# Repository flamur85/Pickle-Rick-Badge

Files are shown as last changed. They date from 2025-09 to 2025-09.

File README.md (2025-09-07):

# Pickle Rick Badge Project

## Description
This project is a custom DIY electronic badge inspired by the DEF CON badge community. The badge brings together lights, sound, and motorized elements to create an interactive show triggered by button presses. It’s both a fun hacker-style project and a learning platform for Raspberry Pi GPIO programming, event handling, and hardware hacking.

Beyond the visual and audio shows, this badge will also include **CTF (Capture the Flag) functionality**, allowing others to explore hidden challenges embedded into the badge’s code, hardware, or connected resources. The goal is to create a hands-on, puzzle-filled badge that fits right into the spirit of hacker conferences.

## Project Image

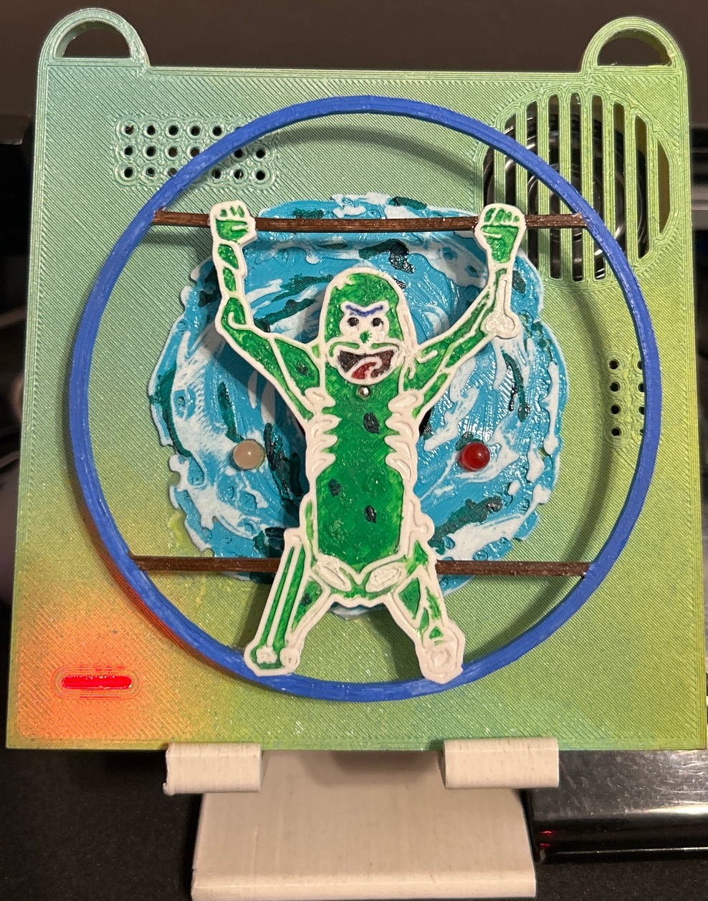
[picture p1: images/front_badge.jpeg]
Pickle Rick Badge


## Materials List
You’ll need the following to build and run the badge:

- **Raspberry Pi Zero 2 W**
- **MicroSD card** flashed with Raspberry Pi OS
- **Push buttons** (x5, GPIO wired)
- **LEDs** (x6, arranged in a circular pattern)
- **Resistors** for LEDs (220Ω or 330Ω recommended for use with Raspberry Pi GPIO)
- **DC hobby motor** (I got one from an old PS4 controller)
- **Diode** (1N4001 or similar, for motor flyback protection)
- **NPN transistor** (PN2222 or similar) for motor control
- **LiPo battery** (3Ah recommended. You can also use the battery from the PS4 controller too, though will not last as long...)
- **Boost converter** (to step up LiPo voltage to 5V for Pi)
- **Small physical single pole sliding switch** (for power control)
- **USB audio interface** (for audio output from the Pi)
- **Small audio amplifier module** (to drive the speaker)
- **Speaker** (8Ω, 0.5W–1W recommended)

For detailed assembly, wiring, and setup instructions, see [BUILD_GUIDE.md](BUILD_GUIDE.md).

## 3D Print Files
3D print files for the badge enclosure are included in this repository. The parts are designed for a Creality Ender 3 Pro and use PETG filament for durability and heat resistance. Feel free to modify or remix the files for your own setup!

## Sounds
A `audio_files` folder is included in this repository, containing the audio files used in the project. These sounds are played during the badge's interactive shows and events. You can replace them with your own audio clips or add new ones to customize your badge experience.

## Features
- **Startup Sound**: Plays "I'm Pickle Rick!" when the Pi boots up.
- **SSH Login Success Sound**: Plays "Son of a B*tch, I'm In!" on successful SSH login.
- **Power Level LEDs**: A set of LEDs displays the current battery level, giving a quick visual indication of remaining power.
- **SSH Login Failure Sound**: Plays "Disqualified!" on unsuccessful SSH login.
- **Power Light Indicator**: An LED illuminates when the badge is powered on, providing a clear visual status.
- **Button 1**: Triggers the *full show* (sound, lights, motor).
- **Button 2**: Triggers the *mini show* (lights + motor only).
- **Other 3 buttons**: Reserved for future expansion, including CTF triggers.
- **CTF Challenges**: Future versions will embed puzzles such as hidden flags in the code, badge interactions, or Easter eggs that encourage reverse engineering, etc.

## Inspired By
The design is inspired by **DEF CON electronic badges** and the broader **badge life community**, where creativity meets hacking culture. These badges often combine art, electronics, and puzzles to create unique experiences. The Pickle Rick Badge follows that tradition by blending fun shows with a CTF challenge element.

## Future CTF Functionality
- Hidden flags inside source code and hardware signals
- Triggered events requiring timing or button sequences
- Audio steganography challenges inside badge sounds
- Network-based puzzles (optional Wi-Fi CTF mode)

---

This project is meant to grow alongside community contributions and ideas. Whether you’re into hardware hacking, Python programming, or CTF puzzle design, this badge offers a platform to experiment and share.

For a step-by-step build walkthrough, see [BUILD_GUIDE.md](BUILD_GUIDE.md).

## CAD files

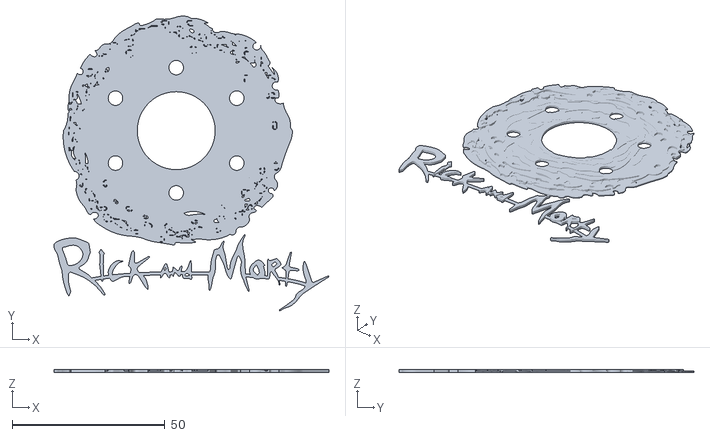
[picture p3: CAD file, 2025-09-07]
3d_print_files/Badge Bling.stl
90.0 x 96.5 x 1

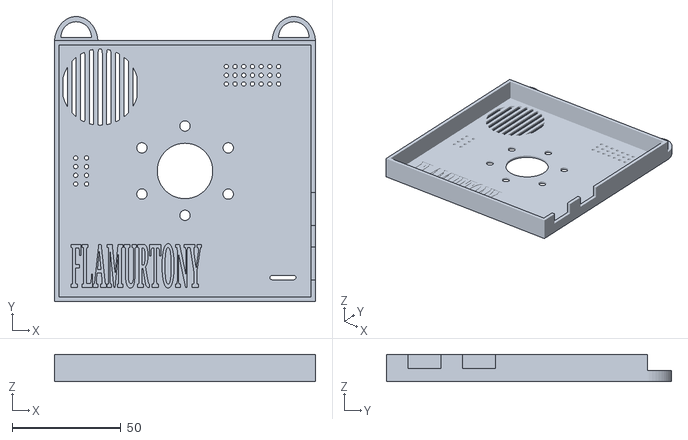
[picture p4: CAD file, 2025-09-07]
3d_print_files/Badge Front v2.stl
120.0 x 131.0 x 12.5

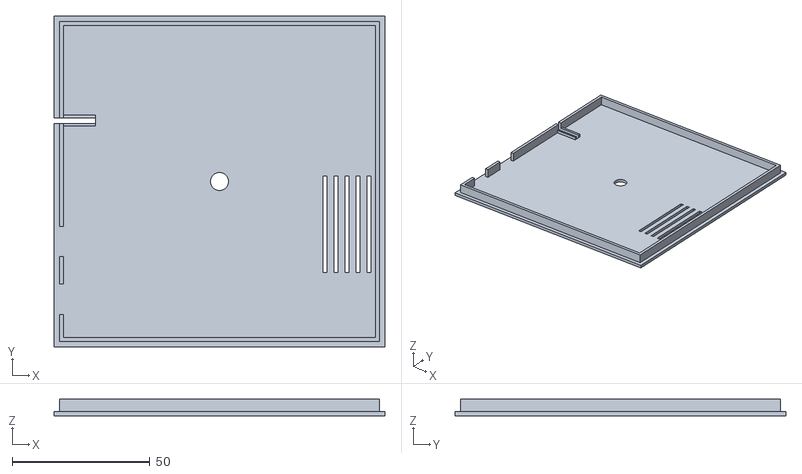
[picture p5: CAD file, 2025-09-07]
3d_print_files/Badge Bottom v2.stl
120.0 x 120.0 x 6.00

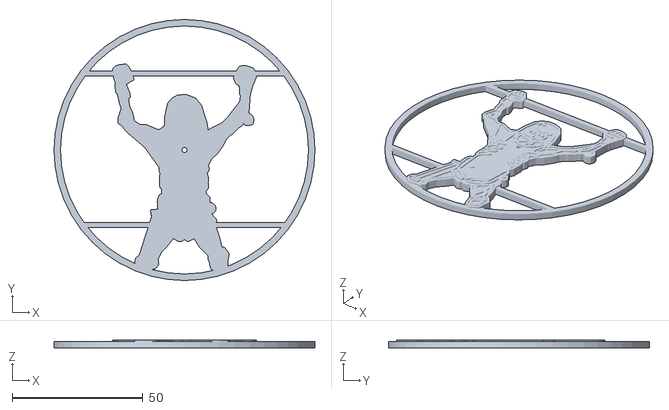
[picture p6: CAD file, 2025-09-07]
3d_print_files/Animal Pickle Rick.stl
100.0 x 100.0 x 3.00

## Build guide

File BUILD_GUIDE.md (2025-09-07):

# Pickle Rick Badge Build Guide

This guide documents how I built my DEFCON Pickle Rick Badge, including hardware, wiring, software setup, and practical tips learned along the way.

---

## 1. What I Built

A Raspberry Pi Zero 2 W powered DIY badge with:

- Boot sound (“I’m Pickle Rick!”) played at startup
- SSH login success/fail sounds (“I’m in” / “Disqualified”)
- 6 LEDs in a ring with patterns
- Vibration motor spinner (PS4 rumble motor) via PN2222A + flyback diode
- Five buttons triggering interactive shows

> **Note:** My Pi username is `admin`. If yours is different, update `/home/admin/…` paths in scripts, services, and configs.

---

## 2. Hardware Used

- **Raspberry Pi Zero 2 W**
- **USB audio dongle** + small amplifier/speaker (or headphones for testing)
- **6× LEDs** with 220–330 Ω resistors
- **5× push buttons** (wired to GND + GPIO, using internal pull-ups)
- **PN2222A (or 2N2222) NPN transistor** for motor control
- **Flyback diode** (1N4001 or 1N4148) across motor
- **Li-ion 3.7V cell + 5V boost module** for power
- **Small physical single pole sliding switch** for power control
- **Flux and solder** for reliable connections
- **Enamelled (magnet) wire** for compact wiring
- **Thin-gauge stranded wire** (e.g., 24–28 AWG) for power and signals
- **Electrical tape or Kapton tape** for insulation
- **Hot glue gun** for securing components and strain relief

**GPIO mapping (my wiring):**

- **LEDs (clockwise):** 26, 5, 13, 6, 19, 22
- **Buttons:** 20, 16, 21, 12, 25
- **Motor (PWM):** 18 (via PN2222A, 1k base resistor, 100k base→GND, diode across motor)

---

## 3. 3D Printing the Enclosure

- Print the enclosure parts from the `3d_print_files` folder.
- I used a Creality Ender 3 Pro with PETG filament for durability and heat resistance.
- Clean up and test-fit all parts before assembly.

---

## 4. Assemble the Electronics

1. **LEDs:** Solder in a circular pattern on your PCB or perfboard.
    - Connect a 220Ω or 330Ω resistor between each GPIO pin and the LED anode (longer leg, +).
    - Connect all cathodes (shorter legs, –) together and run to GND.

2. **Motor:** 
    - Solder the motor’s negative terminal to the collector of the PN2222A transistor.
    - Positive terminal goes to the 5V rail (from boost converter).
    - Emitter to GND.
    - 1kΩ resistor between GPIO18 and transistor base; 100kΩ base to GND.
    - Diode (1N4001 or similar) across motor terminals for flyback protection (stripe/cathode to 5V, anode to collector).

3. **Power Circuit:** 
    - Connect LiPo battery (3Ah recommended) to boost converter, then boost converter’s 5V/GND to Pi.
    - Install sliding switch to interrupt the 5V line before it reaches the Pi for safe power control.

4. **Audio:** 
    - Plug USB audio dongle into Pi.
    - Connect dongle output to amplifier module input.
    - Amplifier output to speaker (8Ω, 0.5W–1W recommended).
    - Power amplifier from 5V rail if supported.
    - Secure speaker so sound can exit the enclosure.

---

## 5. Software Setup

1. Flash Raspberry Pi OS to your microSD card.
2. Clone this repo onto the Pi:
   ```bash
   sudo apt update && sudo apt install -y git
cd ~ && git clone <this-repo-url> .
   cd ~/pickle-rick-badge
   ```
3. Install `mpg123` for MP3 playback:
    ```bash
    sudo apt install -y mpg123
    ```
4. Place your MP3s into `./audio_files` (keep filenames: `pickle_rick_loud.mp3`, `im_in.mp3`, `disqualified.mp3`).
5. Run the installer:
   ```bash
   chmod +x setup.sh
   sudo ./setup.sh
   ```
   - This script sets up:
     - `rc.local` to run your main Python script at boot
     - `startup_sound.sh` to play the boot sound
     - `startup-sound.service` to trigger the boot sound via systemd
     - `ssh-fail-sound.service` to play a sound on failed SSH login
     - Updates `.bashrc` to play a sound on successful SSH login and adds a `py` alias for `python3`
6. Reboot to test boot sound & services:
   ```bash
   sudo reboot
   ```

---

## 6. Final Assembly

- Place all components into the 3D printed enclosure.
- Secure with screws or adhesive as needed.
- Double-check all connections before powering on.

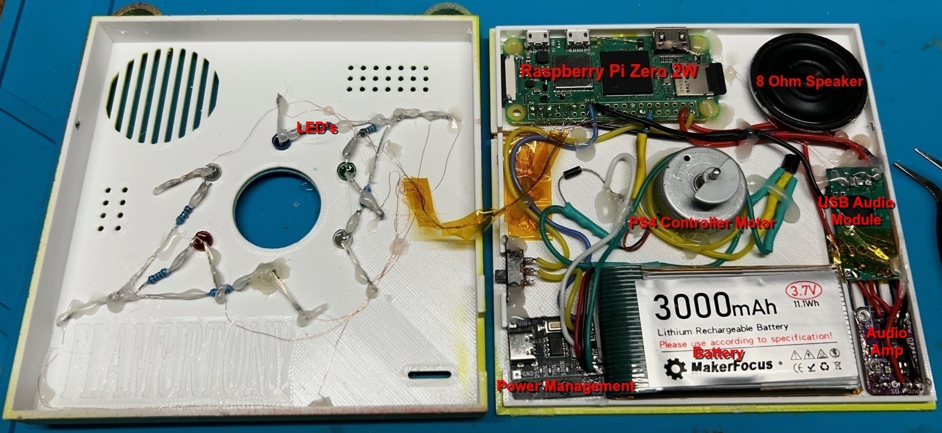
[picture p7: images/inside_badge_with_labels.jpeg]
Badge Assembly Close-up


*Close-up of the badge electronics before enclosure installation.*

---

## 7. Testing

- Power on the badge using the sliding switch.
- Test each button to ensure the correct show or function triggers.
- Check LEDs, motor, and audio output.

---

## Tips & Lessons Learned

- **Never drive motors directly from GPIO.** Always use a transistor and diode.
- **Common ground:** Ensure Pi GND, motor PSU GND, and button/LED grounds are connected.
- Double-check LED and motor polarity.
- Use heat shrink or tape to insulate exposed wires.
- Customize your badge by adding new sounds or modifying the code.
- If you see a “ghost LED on” at boot, use the provided `led_clear.py` tool.
- For safe power control, always cut the positive (V+) output wire from the boost converter with your sliding switch—not the ground.
- Label wires and take photos during assembly for easier troubleshooting.
- Back up your microSD card in case you need to re-flash or recover your setup.

---

Enjoy building and hacking your custom Pickle Rick Badge!

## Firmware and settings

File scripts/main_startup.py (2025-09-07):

from gpiozero import PWMOutputDevice, LED, Button
from time import sleep
import subprocess
import time
from signal import pause
from threading import Lock

motor = PWMOutputDevice(18)

# LEDs on these GPIOs (clockwise)
led_pins = [26, 5, 13, 6, 19, 22]
leds = [LED(pin) for pin in led_pins]

# Buttons
buttons = {
    "Button 1": Button(20),
    "Button 2": Button(16),
    "Button 3": Button(21),
    "Button 4": Button(12),
    "Button 5": Button(25)
}

# Sound file for full show
pickle_rick_long = "/home/admin/audio_files/pr_long.mp3"
ohyea = "/home/admin/audio_files/ohyea_loud.mp3"

# Lock to prevent overlapping shows
show_lock = Lock()

# Reset all LEDs at start
for led in leds:
    led.off()

# Full show: Button 1
def full_show():
    if not show_lock.acquire(blocking=False):
        print("Show already running, wait...")
        return

    try:
        subprocess.Popen(["mpg123", "-q", pickle_rick_long])

        motor.value = 0.25
        print("Full show: Motor ON, LEDs starting...")

        for _ in range(15):
            for led in leds:
                led.on()
                sleep(0.07)
                led.off()
            sleep(0.02)

        motor.off()
        print("Full show: Motor OFF, finishing LEDs...")

        for _ in range(5):
            for led in leds:
                led.on()
            sleep(1)
            for led in leds:
                led.off()
            sleep(1)

        print("Full show complete.")

    finally:
        show_lock.release()

# Mini show: Button 2
def mini_show():
    if not show_lock.acquire(blocking=False):
        print("Show already running, wait...")
        return

    try:
        print("Mini show started!")

        subprocess.Popen(["mpg123", "-q", ohyea])


        pulse_steps = 30 
        duration = 10 
        step_time = duration / (pulse_steps * 2)

        start_time = time.time()
        while time.time() - start_time < duration:
            # Ramp up
            for i in range(pulse_steps):
                motor.value = i / pulse_steps * 0.4 
                # Bouncing LED pattern
                for idx, led in enumerate(leds):
                    if idx % 2 == i % 2:
                        led.on()
                    else:
                        led.off()
                sleep(step_time)

            for i in reversed(range(pulse_steps)):
                motor.value = i / pulse_steps * 0.25
                for idx, led in enumerate(leds):
                    if idx % 2 == i % 2:
                        led.on()
                    else:
                        led.off()
                sleep(step_time)

        motor.off()
        for led in leds:
            led.off()

        print("Mini show complete.")

    finally:
        show_lock.release()

# Assign buttons
buttons["Button 1"].when_pressed = full_show
buttons["Button 2"].when_pressed = mini_show

print("Press Button 1 for full show or Button 2 for mini show.")
pause()

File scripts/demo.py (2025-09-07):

from gpiozero import PWMOutputDevice, LED
from time import sleep
import subprocess
from threading import Lock
import random

motor = PWMOutputDevice(18)
led_pins = [26, 5, 13, 6, 19, 22]
leds = [LED(pin) for pin in led_pins]

pickle_rick_long = "/home/admin/audio_files/pr_long.mp3"

show_lock = Lock()

for led in leds:
    led.off()

def full_show():
    if not show_lock.acquire(blocking=False):
        print("Show already running, wait...")
        return

    try:
        subprocess.Popen(["mpg123", "-q", pickle_rick_long])
        motor.on()
        sleep(0.1)
        motor.off()

        motor.value = 0.1
        print("Full show: Motor ON, LEDs starting...")

        for _ in range(15):
            for _ in range(len(leds)):
                led = random.choice(leds)
                led.on()
                sleep(0.05)
                led.off()
            sleep(0.02)

        motor.off()
        print("Full show: Motor OFF, finishing LEDs...")

        for _ in range(10): 
            for led in leds:
                led.on()
            sleep(0.3)
            for led in leds:
                led.off()
            sleep(0.3)

        print("Full show complete.")

    finally:
        show_lock.release()

if __name__ == "__main__":
    full_show()
